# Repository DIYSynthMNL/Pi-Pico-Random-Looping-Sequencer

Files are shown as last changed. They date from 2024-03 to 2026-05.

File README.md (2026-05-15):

# Pi Pico Random Looping Sequencer

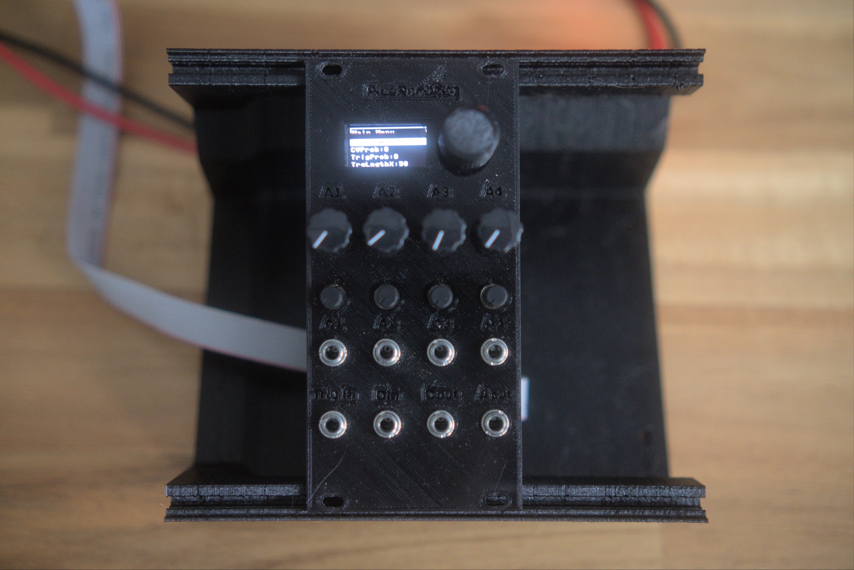
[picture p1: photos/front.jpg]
Pi Pico Random Looping Sequencer powered on


A Raspberry Pi Pico-based Eurorack random / quantized step sequencer with OLED menu, rotary encoder navigation, and **probability-driven variation** on both the CV and trigger sequences. The headline trick: each clock pulse, a configurable probability determines whether the current step's CV (or trigger) gets replaced by a new random value from the chosen musical scale — so the sequence "loops" but slowly mutates as you patch.

Build notes and write-ups on the blog: [diysynthmnl.github.io](https://diysynthmnl.github.io/)

[Demo video on YouTube](https://youtu.be/u1J9JrJe1Y0)

## Features

**Sequencer (firmware):**
- 1 to 16 steps per sequence, user-selectable
- 40+ musical scales (major, minor, dorian, phrygian, blues, pentatonic, hungarian minor, harmonic major, … via [Hector Miller-Bakewell's musical-scales library](https://github.com/hmillerbakewell/musical-scales))
- 1–5 octave CV range
- **CV probability of change** (0–100 %, increments of 5) — how often each step's pitch gets re-randomized on the clock pulse
- **Trigger probability of change** (0–100 %) — same for the trigger output
- **Trigger length** (0–100 % of clock period) — controls gate width
- **CV erase mode** — clamps all steps to scale's root note
- **Trigger erase mode** — sets all triggers to ON
- **Test scale mode** — cycles through scale notes in order (for tuning verification)
- **Tuning scale mode** — alternates between note 12 (1V) and note 24 (2V) (for octave-spacing verification)

**Hardware:**
- 128×64 px SSD1306 OLED display for the menu
- Rotary encoder with push-switch for navigation
- 4 analog parameter inputs (each with jack + attenuator pot + offset pot) → Pico ADC pins
- 1 trigger/clock input
- 1 digital input (for sync, reset, or any gate-like signal)
- 1 digital output (trigger out, with single-transistor buffer to ±5V Eurorack levels)
- 1 quantized CV output via **MCP4725** 12-bit I²C DAC (1V/oct over 5 octaves)
- Eurorack ±12V power (16-pin IDC); local +5V and −5V regulators on board

## Inputs and outputs

| Jack | Function | Wiring |
|---|---|---|
| Analog In 1–4 | Parameter modulation inputs (±5V CV) | Jack → atten (100K) + offset (10K) → MCP6004 → Pico ADC pins GP26–29 |
| Trigger / Clock In | External clock or trigger | Jack → 100K + BAT42 clamps → 2N3904 inverter → GP22 |
| Digital In | Generic digital input (sync, reset, …) | Same topology → GP21 |
| Digital Out | Trigger / gate output | GP23 → 100K → 2N3904 inverter → 10K + 100K → jack |
| vOct Out | Quantized CV (0–5V, 1V/oct) | MCP4725 DAC (I²C, address 0x60) → 100K series → jack |

Front-panel pots / controls:

| Control | Value | Function |
|---|---|---|
| RV2 / RV4 / RV6 / RV8 | 100K | **Analog input attenuator** per channel (1–4) |
| RV1 / RV3 / RV5 / RV7 | 10K | **Analog input offset** per channel (1–4) |
| SW1 | rotary encoder + switch | **Menu navigation** — rotate to scroll items, click to select |

## Pico GPIO pinout (Rev 0.1.0)

| GP | RP2040 function | Connected to | Notes |
|---|---|---|---|
| GP16 | I²C0 SDA | OLED + MCP4725 | Shared bus, both peripherals (addresses 0x3C and 0x60) |
| GP17 | I²C0 SCL | OLED + MCP4725 | Same |
| GP18 | GPIO | Rotary encoder A | |
| GP19 | GPIO | Rotary encoder B | |
| GP20 | GPIO | Rotary encoder switch | Active-low (button to GND) |
| GP21 | GPIO | Digital input | **Inverted** by Q2 2N3904 |
| GP22 | GPIO | Trigger/Clock input | **Inverted** by Q1 2N3904 |
| GP23 | GPIO | Digital output | Drives Q3 2N3904 → jack tip |
| GP26 (ADC0) | ADC | Analog In 4 (per firmware mapping) | |
| GP27 (ADC1) | ADC | Analog In 3 | |
| GP28 (ADC2) | ADC | Analog In 2 | |
| GP29 (ADC3) | ADC | Analog In 1 | **Requires Pico clone with GP29 broken out — see Build notes below** |

## Block diagram

```
                  ╔══════════════════════ HARDWARE ════════════════════╗
                  ║                                                       ║
External CV (±5V) ──[J1–J4]──┬──[RV (100K) atten]──┐                    ║
                              │                    ▼                     ║
                              ▼               [R (100K) summing]         ║
                          [RV (10K) offset]   │                          ║
                               │              │                          ║
                          [+5V/−5V refs]      ▼                          ║
                               │       [MCP6004 inverting amp]           ║
                               └─────────────┤                           ║
                                              │                          ║
                                              ▼ (0 to 3.3V)              ║
                                       Pico GP26–29 (ADC)                 ║
                                                                          ║
Trigger jack ── inverter ──► GP22                                         ║
Digital In   ── inverter ──► GP21                                         ║
                                                                          ║
                  ╔════════════════════ FIRMWARE (MicroPython) ═════════╗
                  ║                                                       ║
                  ║  main loop:                                           ║
                  ║    main_menu.loop_main_menu(update_seq_callback)      ║
                  ║    handle_clock_pulse()  ← detects GP22 edges        ║
                  ║       on rising edge:                                 ║
                  ║         randomly_change_current_step_cv()             ║
                  ║         randomly_change_step_trigger()                ║
                  ║         dac.write(cv_sequence[current_step])          ║
                  ║         current_step += 1 (mod number_of_steps)       ║
                  ║    check_trigger_off()  ← turns off trigger after     ║
                  ║                            trigger_length_ms          ║
                  ║                                                       ║
                  ║  sequencer state:                                     ║
                  ║    cv_sequence[16] = quantized 12-bit DAC values      ║
                  ║    trigger_sequence[16] = 0/1                         ║
                  ║    current_12bit_scale = scale × octaves              ║
                  ║                                                       ║
                  ╚═══════════════════════════════════════════════════════╝
                                              │                          ║
                                              ▼                          ║
GP23 ──► inverter ──► Digital Out jack                                    ║
                                                                          ║
GP16/17 (I²C0) ──► MCP4725 DAC ──► [R23 100K series] ──► vOct Out jack    ║
                                                                          ║
                  ╚═══════════════════════════════════════════════════════╝
```

## Power

- Eurorack ±12V via **J7** (16-pin IDC)
- D6 / D7: reverse-polarity protection
- C4 / C5 (22 µF): bulk rail decoupling on ±12V
- **U3 (78M05): +5V regulator** from +12V → powers MCP4725, Pico VSYS (via D5 BAT42), OLED, transistor pull-ups
- **U4 (79M05): −5V regulator** from −12V → powers the analog input offset network (−5V reference)
- Pico generates its own **+3.3V** (from VSYS via on-board buck converter on the Pico module) → powers MCP6004 op-amps
- C1 / C6 (2.2 µF) regulator output caps, C7 / C3 (100 nF) decoupling

Two power scenarios are supported:
1. **Eurorack power only** — module operates fully
2. **Eurorack + USB** — Pico's USB port can be plugged in concurrently for firmware development. **D5 (BAT42 between +5V rail and Pico VSYS)** prevents USB from back-feeding the Eurorack rail, and prevents Eurorack from feeding the USB host.

## Build notes

### Choose a Pi Pico clone with GP29 (ADC3) broken out

> **This is the most important build decision.** The official Raspberry Pi Pico has GP29 internally tied to VSYS voltage sensing and **is NOT available as an ADC pin**. Many Pico clones (including the one shown in this design, the "Pi Pico Clone Lite Black") break out all 4 ADC pins, including GP29.
>
> If you can't find a clone with GP29 exposed, you have two options:
> - **Reduce to 3 analog inputs** in firmware — omit `cv1 = AnalogueReader(A3)` in `main.py` and adjust the menu / mapping accordingly. The hardware would still have all 4 jacks but the 4th would be unconnected at the Pico.
> - **Use an external ADC** (e.g., MCP3208 over SPI) for the analog inputs — more flexible but requires firmware rework.

Compatible clones tested:
- "Pi Pico Clone Lite Black" — confirmed to have GP29 broken out (used in this design)
- Other clones: check the pinout diagram before buying

### Component selection

- **MCP4725 breakout board** (J8) — common Adafruit / generic breakout, uses I²C address 0x60 (or 0x61, depending on A0 pin). Comes pre-soldered.
- **SSD1306 128×64 OLED** (J… U5) — common eBay / Aliexpress breakout, I²C address 0x3C.
- **MCP6004 quad op-amp** (U1) — rail-to-rail CMOS, runs on +3.3V single supply. DO NOT substitute a TL07x here — those won't swing rail-to-rail and won't reach 0V on the output.

## Calibration

The module has no internal hardware trim pots — calibration is done in software via the firmware's tuning modes.

**Step 1 — Verify 1V/oct tracking using Tuning Scale mode.**

The firmware has a "TuningScale" toggle in the menu. When enabled, it outputs a fixed alternating sequence:

| Step | 12-bit DAC value | Expected voltage at DAC output |
|---|---|---|
| 0 | 816 | 1.000 V (note 12 = first C above 0V) |
| 1 | 1632 | 2.000 V (note 24 = second C) |
| 2 | 816 | 1.000 V |
| ... | ... | ... |

Procedure:
1. Enable TuningScale mode in the menu
2. Patch any clock signal into Trigger/Clock In
3. Scope the vOct Out jack — the output should toggle between two voltages exactly **1.000 V apart**
4. If the spacing is not 1.000 V (typically slightly less, e.g. 0.996 V), the DAC's Vref is slightly off from 5.000 V — see **Design notes — 1V/oct precision** for the math and fix options

**Step 2 — Verify GP29 (ADC3) is working.**

If you're using a clone with GP29 exposed, patch a CV into Analog In 1 (which maps to GP29 / ADC3 per the firmware) and verify it shows up correctly in any analog-input-driven menu (note: as of Rev 0.1.0 of the firmware, analog inputs are wired to hardware but the main loop's analog reading code is `TODO`'d out — see [issue #2](../../issues)).

## Development workflow

1. Power the module via Eurorack (±12V)
2. Plug a USB cable into the Pico (this is safe; D5 prevents back-feeding)
3. Use **VSCode with the [MicroPico extension](https://marketplace.visualstudio.com/items?itemName=paulober.pico-w-go)**
4. Common commands:
   - `MicroPico: Delete all files from pico` — wipe before fresh upload
   - `MicroPico: Upload project files to pico` — sync `Software/` to the Pico
   - `MicroPico: Run` — execute `main.py`

The Pico runs **MicroPython** firmware (not C/C++ SDK). MicroPython is slower but dramatically easier to iterate on — and the timing precision required for a step sequencer (a few ms of clock-edge accuracy) is well within MicroPython's capabilities on the RP2040.

### C++ rewrite (in progress)

A C++ rewrite of the firmware — host-agnostic `SequencerEngine` class plus a macOS playground simulator, with a Pico-SDK host planned — lives in its own repo: [**DIYSynthMNL/Pi-Pico-Random-Looping-Sequencer-Firmware**](https://github.com/DIYSynthMNL/Pi-Pico-Random-Looping-Sequencer-Firmware). The MicroPython firmware in `Software/` is still the running firmware on hardware today.

## Borrowed firmware libraries

Two external libraries are vendored into `Software/lib/`:

- **`analog_reader.py`** — adapted from [EuroPi by Allen Synthesis](https://github.com/Allen-Synthesis/EuroPi) (Apache License 2.0). `AnalogueReader` class with `percent()`, `range()`, `choice()` helpers and over-sampling for noise reduction. Local additions: `invert` flag, `map_value()` helper.
- **`mcp4725_musical_scales.py`** — built on top of [Hector Miller-Bakewell's musical-scales](https://github.com/hmillerbakewell/musical-scales) library (MIT). Defines 40+ scale intervals and a `get_scale_of_12_bit_values()` helper that converts note numbers to MCP4725 DAC counts.

Other vendored libs (`ssd1306.py`, `rotary.py`, `rotary_irq_rp2.py`, `mp_button.py`, `mcp4725.py`) are standard MicroPython drivers — credited in each file's header.

Original code: `main.py`, `menu.py` (custom OLED menu system), `musical_scales.py` (Rex's wrapper around the above).

## Design notes

### 1V/oct precision math

The MCP4725 is a 12-bit DAC with Vref = VCC = 5V (powered from the local 78M05 regulator). Resolution: 5V / 4096 = **1.221 mV per count**.

For 1V/oct over 12 semitones, the ideal step is **83.33 mV per semitone**. The firmware uses `multiplier = 68` counts per semitone → 68 × 1.221 mV = **82.99 mV per semitone** — that's 0.34 mV short, or about **7 cents flat per octave**. Compounded over 5 octaves at the top of the range: ~35 cents flat at the top C.

Fix options (in order of effort):
1. **Use a tuning lookup table** in firmware that adjusts each note's DAC count individually — captures the per-octave error. Requires bench-measured calibration data.
2. **Trim the +5V regulator's output** slightly high (e.g., to 5.083 V) so 4080 counts = 5.000 V exactly. But this affects the OLED and the digital output level too.
3. **Add a 1V/oct gain trim** in hardware: replace R23 with an op-amp buffer + gain trim that scales the DAC output up by ~0.4 %. This is the canonical Eurorack approach.

### MCP4725 output buffering

R23 (100K) is the only thing between the DAC's output pin and the vOct Out jack — **there is no buffer op-amp.** With a typical Eurorack input impedance of 100K, this forms a 1:1 voltage divider that **halves the output voltage**.

**This is a real concern** — needs bench verification:
- Scope J9 with no load → should match the DAC voltage (no divider)
- Scope J9 driving a typical 100K Eurorack input → if voltage is halved, you have ~0.5 V/oct instead of 1 V/oct
- Fix: insert a unity-gain TL07x buffer between the DAC output and R23 (or replace R23 with the buffer)

See [issue #1](../../issues).

### Analog input mapping

The MCP6004 op-amps run from +3.3V single supply. Their output must stay within 0–3.3V to be readable by the Pico's ADC. The input network does the mapping:

```
External CV (±5V) ──[100K attenuator (RV2 fully open)]──┐
                                                        │
+5V/−5V offset ──[10K offset pot]──[100K]──┐            │
                                            │            ▼
                                            ▼      [100K input R]
                                       [100K input R]    │
                                            └───────────┤
                                                        │
                                       (inverting summing junction)
                                                        │
                                                        ▼
                                           [MCP6004 inverting amp, 100K feedback]
                                                        │
                                                        ▼
                                                  Pico ADC (0–3.3V)
```

The math is: at the inverting input, the contributions sum. The op-amp output is `−(V_in/100K + V_offset/100K) × 100K = −(V_in + V_offset)`. With a +5V supply and clamping to 0–3.3V, the effective input range is roughly `+1.7V to −3.3V` external → `0V to 3.3V` at the ADC. This is asymmetric — the input is biased toward processing positive-going CVs.

For symmetric ±5V CV mapping, the offset pot RV1/3/5/7 should be set to bias the op-amp output near 1.65V (mid-range) at 0V external input. Calibration procedure for this is currently undocumented — see [issue #3](../../issues).

## Inspirations and prior art

This module sits in the "random / generative sequencer" family. Direct inspirations:
- **EuroPi (Allen Synthesis)** — the analog reading pattern is borrowed from here; EuroPi is the open-source progenitor of "Pi Pico + Eurorack" modules
- **Music Thing Modular Turing Machine** — the "looping but mutating" concept (Rex's "probability of change" is structurally similar to Turing's "lock probability")
- **Mutable Instruments Marbles** — random CV + trigger generation with probability-of-change parameters

This module is **MicroPython on a Pi Pico** — simpler firmware than EuroPi (which is a full Allen-Synthesis-maintained framework) but with comparable hardware capability.

## References

Local archived copies live in [`references/`](references/) so this repo stays useful if the upstream links die.

- **RP2040 datasheet (Raspberry Pi)** — [local copy](references/RP2040-datasheet.pdf) · [upstream](https://datasheets.raspberrypi.com/rp2040/rp2040-datasheet.pdf)
- **MCP4725 datasheet (Microchip)** — [local copy](references/MCP4725-Microchip.pdf) · [upstream](https://ww1.microchip.com/downloads/en/devicedoc/22039d.pdf) — 12-bit DAC, I²C
- **MCP6001/2/4 datasheet (Microchip)** — [local copy](references/MCP6001-2-4-Microchip.pdf) · [upstream](https://ww1.microchip.com/downloads/aemDocuments/documents/MSLD/ProductDocuments/DataSheets/MCP6001-1R-1U-2-4-1-MHz-Low-Power-Op-Amp-DS20001733L.pdf) — covers the MCP6004 quad op-amp
- [Raspberry Pi Pico full datasheet (with on-module Pico-specific info)](https://datasheets.raspberrypi.com/pico/pico-datasheet.pdf) — not archived locally (17 MB), but worth bookmarking
- [EuroPi project (Allen Synthesis)](https://github.com/Allen-Synthesis/EuroPi) — `analog_reader.py` source
- [musical-scales library (Hector Miller-Bakewell)](https://github.com/hmillerbakewell/musical-scales) — `mcp4725_musical_scales.py` source
- [Build blog: diysynthmnl.github.io](https://diysynthmnl.github.io/) — Rex's running notes on this build

## Build status

What's ready for builders today, and what's still on the TODO list:

**Production assets** (what you need to actually fabricate and assemble a final unit)

- [x] Schematic — Rev 0.1.0 ([pi-pico-random-looping-sequencer-schematic-rev-0.1.0.pdf](Hardware/Schematics/pi-pico-random-looping-sequencer-schematic-rev-0.1.0.pdf))
- [ ] PCB layout — in progress — single working layout in `Hardware/pi-pico-random-looping-sequencer/`, not yet separated for fab
- [ ] Gerber files for fabrication — none yet
- [ ] BOM — none yet
- [ ] Final front panel (SVG/PDF for fab) — none yet
- [x] License — [LICENSE](LICENSE) (MIT)

**Prototype assets** (for breadboard / perfboard / 3D-printed-panel builds before final PCB)

- [x] 3D-printed prototype panel STL — [pico-rand-loop-V2.stl](Hardware/3D%20printed%20panel/pico-rand-loop-V2.stl)

**Firmware**

- [x] Working sequencer firmware — [`Software/main.py`](Software/main.py)
- [x] MicroPython libraries vendored in [`Software/lib/`](Software/lib/)
- [ ] Implement reading from the 4 analog input jacks (currently TODO in main loop — see [issue](../../issues))
- [ ] Per-note tuning lookup table (improves 1V/oct precision — see Design notes)
- [ ] Save/load patterns to flash (currently lost on power-cycle)

**Documentation**

- [x] Photos of the assembled module — see [photos/](photos/)
- [x] Demo video — [watch](https://youtu.be/u1J9JrJe1Y0)
- [ ] Build / assembly instructions — none yet
- [x] Calibration procedure — see Calibration section above

Want to help fill a gap (build photos, gerbers, an assembly guide)? Open an issue or PR.

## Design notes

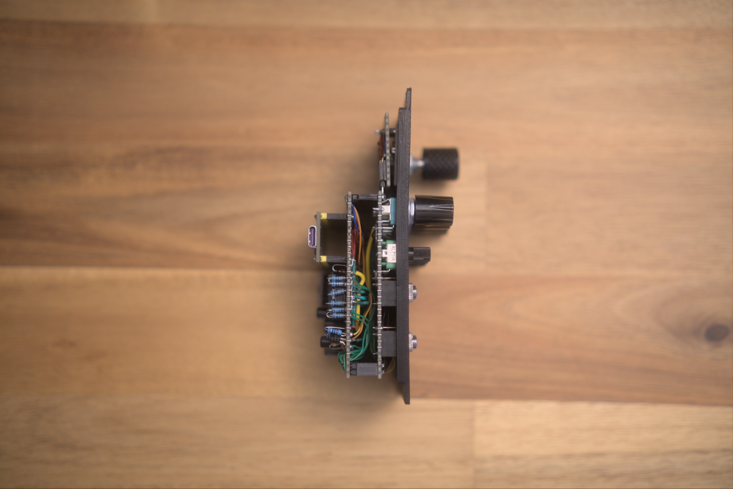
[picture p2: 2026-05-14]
photos/prototype-board-side.jpg

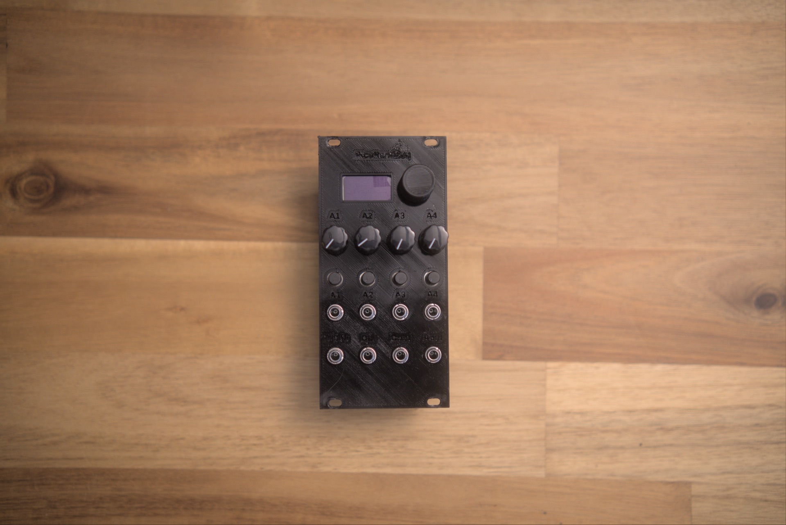
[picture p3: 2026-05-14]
photos/front-flat.jpg

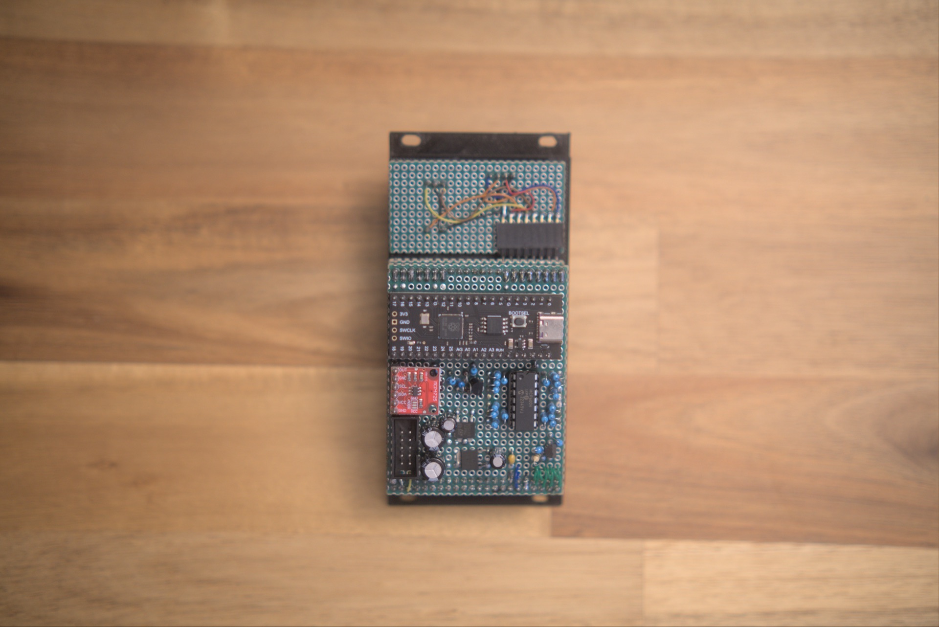
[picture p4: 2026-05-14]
photos/prototype-board.jpg

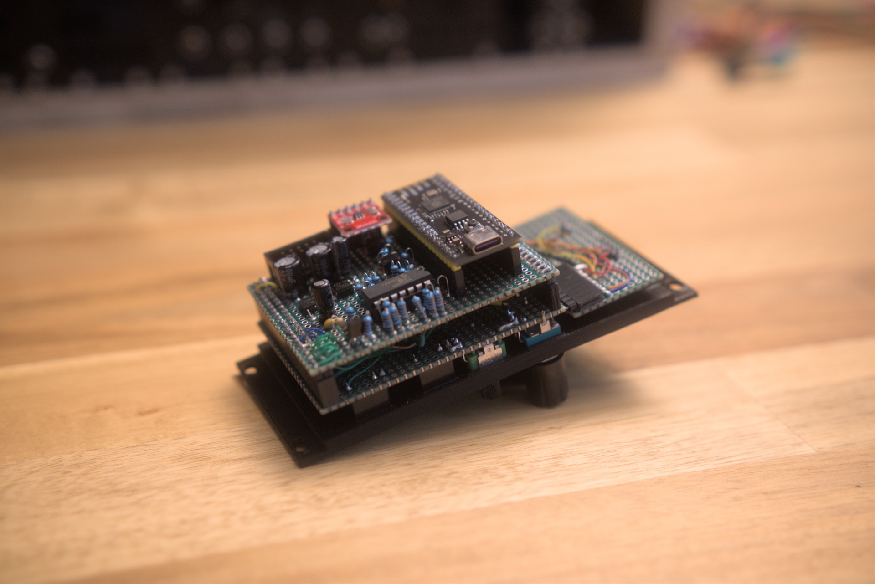
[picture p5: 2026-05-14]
photos/prototype-board-angled.jpg

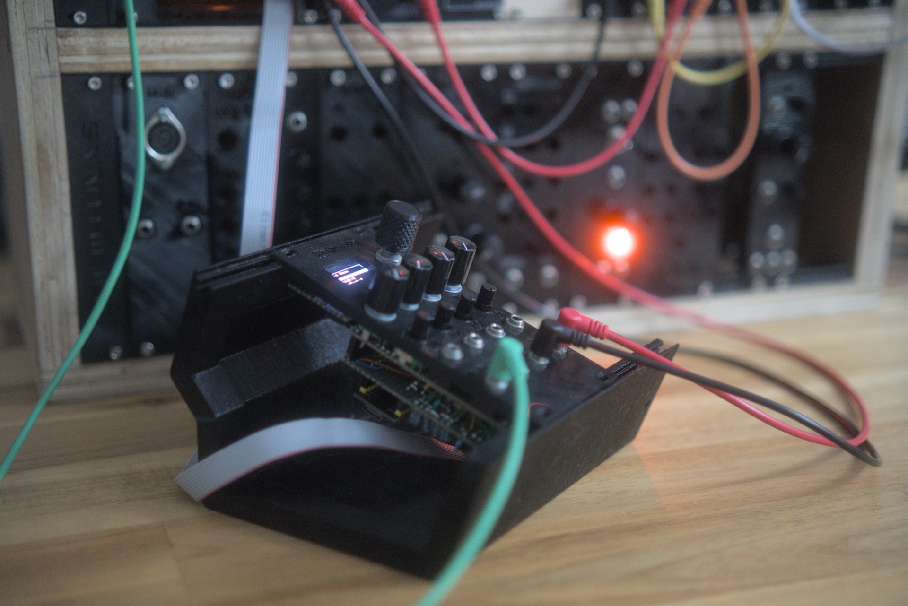
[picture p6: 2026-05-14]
photos/in-rack.jpg

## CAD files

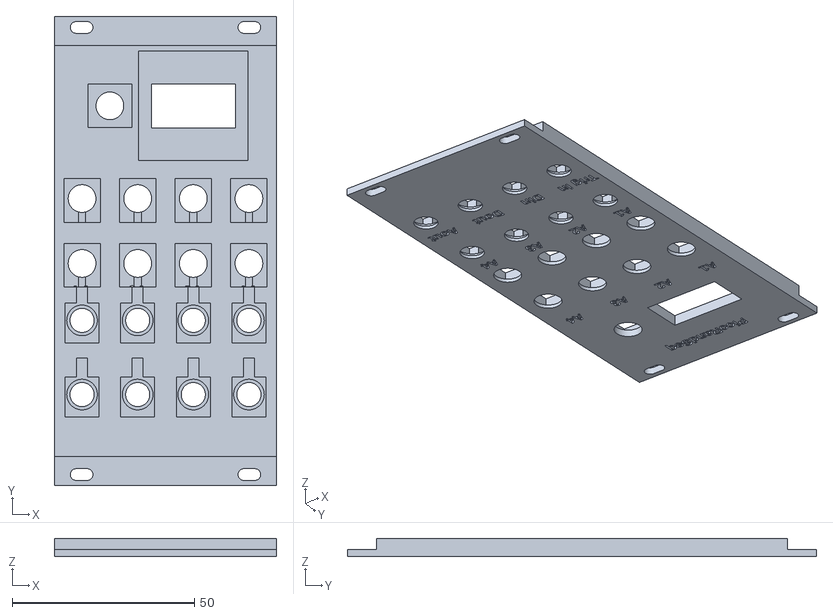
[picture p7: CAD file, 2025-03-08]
Hardware/3D printed panel/pico-rand-loop-V2.stl
61.0 x 128.5 x 5.00

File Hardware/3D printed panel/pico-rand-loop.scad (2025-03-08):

include <EuroPanelMaker/panel.scad>

hp = 12;
title = "PicoRandSeq";
title_font_size = 3;
title_font = "Alte Haas Grotesk:style=bold";
label_font = "Alte Haas Grotesk:style=bold";

panel_flipped=true;
pin_alignment_mode = true;
vertical_mode_254 = true;

jacks = [
[1.5, 16, "A1"],
[4.5, 16, "A2"],
[7.5, 16, "A3"],
[10.5, 16, "A4"],

[1.5, 8, "Trig In"],
[4.5, 8, "Din"],
[7.5, 8, "Dout"],
[10.5, 8, "Aout"],
];

encoders = [
[9, 38, ""] // encoder
];

pots_rd901f = [
// Level
[1.5, 28, "A1"],
[4.5, 28, "A2"],
[7.5, 28, "A3"],
[10.5, 28, "A4"],


// Amplitude
[1.5, 21, ""], //A1
[4.5, 21, ""], //A2
[7.5, 21, ""], //A3
[10.5, 21, ""], //A4
];

rectangular_holes = [
//ssd1306 128x64 px
[4.5, 104, 23, 12, 30, 30]
];
generatePanel();

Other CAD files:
Hardware/3D printed panel/pico-rand-loop.stl

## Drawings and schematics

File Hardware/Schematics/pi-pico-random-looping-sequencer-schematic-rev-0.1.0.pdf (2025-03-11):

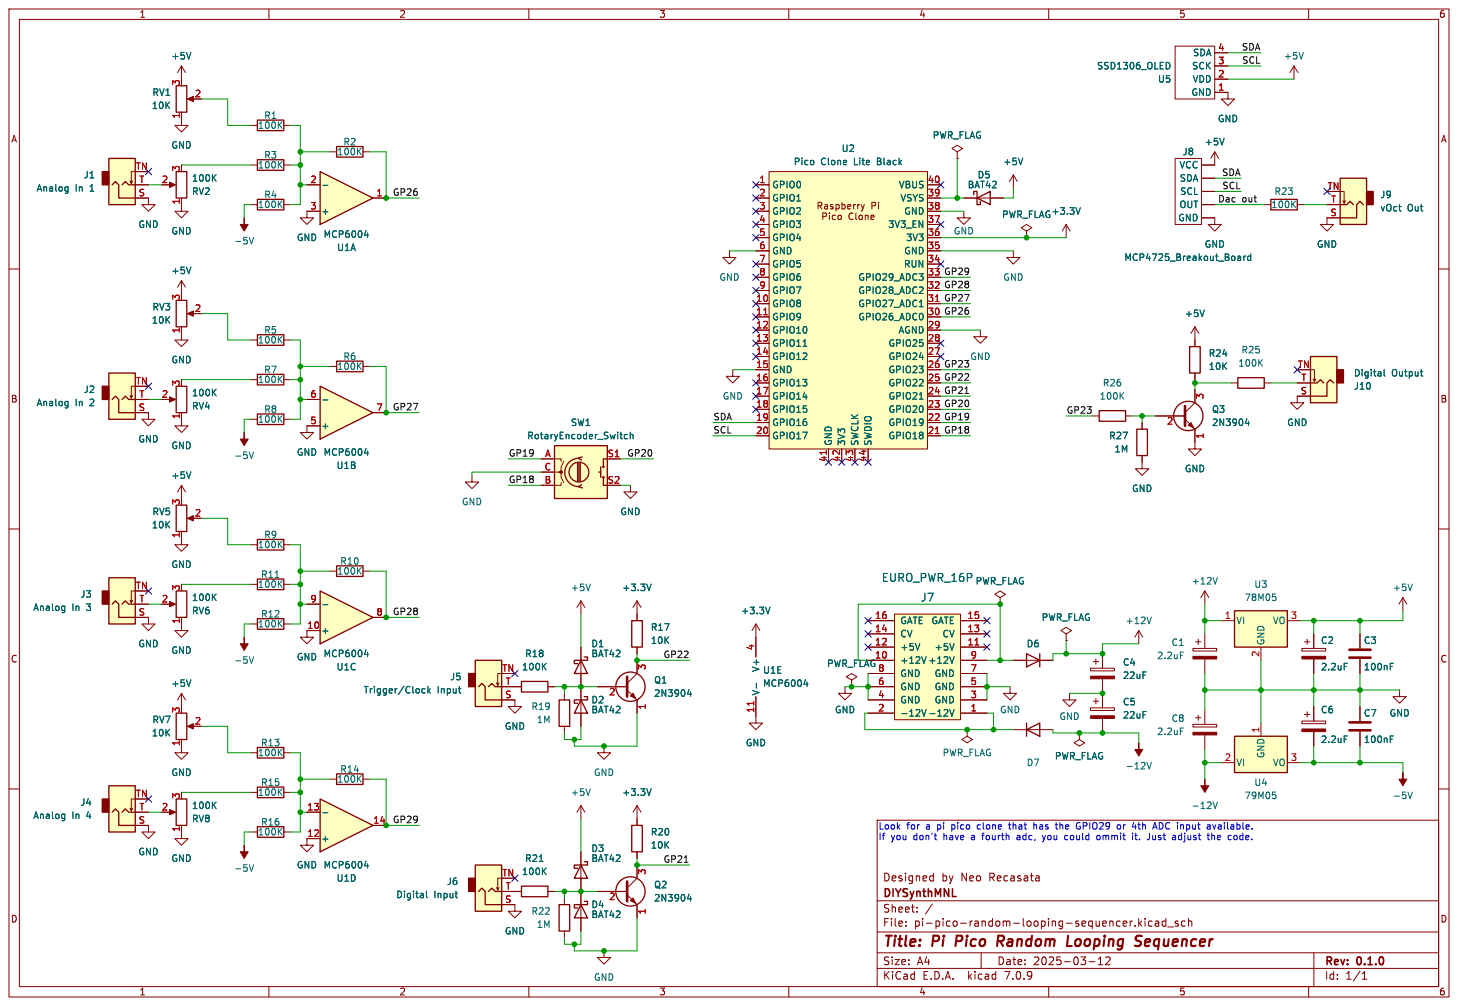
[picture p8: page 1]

J8 MCP4725_Breakout_Board +5V GND
J8 MCP4725_Breakout_Board GND OUT SCL SDA

If you don't have a fourth adc, you could ommit it. Just adjust the code. PWR_FLAG

Look for a pi pico clone that has the GPIO29 or 4th ADC input available.

Id: 1/1 Title: Pi Pico Random Looping Sequencer File: pi-pico-random-looping-sequencer.kicad_sch Sheet: / DIYSynthMNL

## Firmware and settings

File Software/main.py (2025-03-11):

"""
MIT License (MIT)
Copyright (c) 2025 Neo Recasata
https://opensource.org/licenses/MIT

Pi Pico Quantized Random Looping Sequencer (with 128x64 px OLED screen)
By DIYSynthMNL

Wiring:
OLED
OLED SDA to GP16
OLED SCL to GP17
OLED VCC to 3.3V (TODO test 5V)
OLED GND to GND

DAC
DAC SDA to GP16
DAC SCL to GP17
DAC VCC to 5V
DAC GND to GND

Encoder (no breakout board)
ROT Pin 1 to GP19
ROT Pin 2 to GND
ROT Pin 3 to GP18
SW Pin 1 to GND
SW Pin 2 to GP20

Analog inputs
A0 = GP26
A1 = GP27
A2 = GP28
A3 = GP29

TODO: implement control voltage input to change variables
TODO: Schematic
"""

import machine
import mcp4725
import mcp4725_musical_scales as sc
import random
import menu as m
import analog_reader as analog_reader
from analog_reader import AnalogueReader
import time

# pins
sda = 16
scl = 17
digital_input_pin = 21  # inverted
clock_input_pin = 22  # inverted
digital_output_pin = 23  # inverted
A0 = 26
A1 = 27
A2 = 28
A3 = 29

# i2c
i2c_channel = 0
i2c = machine.I2C(i2c_channel, sda=machine.Pin(sda), scl=machine.Pin(scl))
dac = mcp4725.MCP4725(i2c, mcp4725.BUS_ADDRESS[0])

# setup pins
clock_in = machine.Pin(clock_input_pin, machine.Pin.IN, machine.Pin.PULL_DOWN)
digital_in = machine.Pin(digital_input_pin, machine.Pin.IN, machine.Pin.PULL_DOWN)
digital_out = machine.Pin(
    digital_output_pin, machine.Pin.OUT, machine.Pin.PULL_DOWN, value=0
)

# sequencer variables
MAX_NUMBER_OF_STEPS = 16
MIN_NUMBER_OF_STEPS = 2
MAX_NUMBER_OF_OCTAVES = 5
MIN_NUMBER_OF_OCTAVES = 1
cv_sequence = []
trigger_sequence = []
tuning_cv_sequence = [
    816,
    1632,
    816,
    1632,
    816,
    1632,
    816,
    1632,
    816,
    1632,
    816,
    1632,
    816,
    1632,
    816,
    1632,
]
test_cv_sequence = []
current_step = 0
number_of_steps = 16  # user can edit from 1 to any
step_changed_on_clock_pulse = False
cv_probability_of_change = 0  # user can edit 0 to 100
trigger_probability_of_change = 0
trigger_length_percent = 50
trigger_start_ticks = 0
previous_clock_ticks = 0
trigger_active = False
clock_ms = 0
trig_length_ms = 0
ticks_to_trigger_off = 0
is_cv_erase = False
is_trig_erase = False
is_test_cv_sequence = False
is_tuning_cv_sequence = False

# scales
scale_intervals = sc.get_intervals()
current_scale_interval = "major"
starting_note = 12  # start at the next octave to prevent low voltage output issues (the note 0 will not be in tune) refer to the mcp4725 1vOct table
number_of_octaves = 1
current_12bit_scale = sc.get_scale_of_12_bit_values(
    scale_interval=current_scale_interval,
    starting_note=starting_note,
    octaves=number_of_octaves,
)

# menu
main_menu = m.MainMenu()

scale_menu = m.SingleSelectVerticalScrollMenu(
    "Scale",
    button=main_menu.button,
    selected=current_scale_interval,
    items=scale_intervals,
)

cv_prob_menu = m.NumericalValueRangeMenu(
    "CVProb", button=main_menu.button, selected=cv_probability_of_change, increment=5
)

trig_prob_menu = m.NumericalValueRangeMenu(
    "TrigProb",
    button=main_menu.button,
    selected=trigger_probability_of_change,
    increment=5,
)

trig_length_menu = m.NumericalValueRangeMenu(
    "TrgLngth%",
    button=main_menu.button,
    selected=trigger_length_percent,
    increment=10,
)

steps_menu = m.NumericalValueRangeMenu(
    "Steps",
    button=main_menu.button,
    selected=number_of_steps,
    increment=1,
    min_val=MIN_NUMBER_OF_STEPS,
    max_val=MAX_NUMBER_OF_STEPS,
)

octaves_menu = m.NumericalValueRangeMenu(
    "Octaves",
    button=main_menu.button,
    selected=number_of_octaves,
    increment=1,
    min_val=MIN_NUMBER_OF_OCTAVES,
    max_val=MAX_NUMBER_OF_OCTAVES,
)

starting_note_menu = m.NumericalValueRangeMenu(
    "Start note",
    button=main_menu.button,
    selected=0,
    increment=1,
    min_val=0,
    max_val=36,
)

cv_erase_toggle_menu = m.ToggleMenu(
    "CvErase", button=main_menu.button, value=is_cv_erase
)

trig_erase_toggle_menu = m.ToggleMenu(
    "TrigErase", button=main_menu.button, value=is_trig_erase
)

test_cv_scale_toggle_menu = m.ToggleMenu(
    "TestScale", button=main_menu.button, value=is_test_cv_sequence
)

is_tuning_cv_scale_menu = m.ToggleMenu(
    "TuningScale", button=main_menu.button, value=is_tuning_cv_sequence
)

submenus = [
    scale_menu,
    cv_prob_menu,
    trig_prob_menu,
    trig_length_menu,
    steps_menu,
    octaves_menu,
    starting_note_menu,
    cv_erase_toggle_menu,
    trig_erase_toggle_menu,
    test_cv_scale_toggle_menu,
    is_tuning_cv_scale_menu,
]
main_menu.set_submenus(submenu_list=submenus)

# analog inputs
cv1 = AnalogueReader(A3)
cv2 = AnalogueReader(A2)
cv3 = AnalogueReader(A1)
cv4 = AnalogueReader(A0)


def handle_clock_pulse() -> None:
    global current_step, step_changed_on_clock_pulse, clock_in, number_of_steps, previous_clock_ticks, clock_ms, trigger_start_ticks, trigger_active, ticks_to_trigger_off

    current_clock_ticks = time.ticks_ms()

    if current_step < number_of_steps:
        if clock_in.value() == 0 and not step_changed_on_clock_pulse:
            # Clock rising edge detected
            previous_clock_ticks = current_clock_ticks
            test_cv_sequence = get_test_sequence()  # Update CV sequence
            step_changed_on_clock_pulse = True

            randomly_change_current_step_cv()
            randomly_change_step_trigger()

            if is_cv_erase:
                cv_sequence[current_step] = current_12bit_scale[0]

            if is_trig_erase:
                trigger_sequence[current_step] = 1

            # Output the CV value
            if is_test_cv_sequence:
                dac.write(test_cv_sequence[current_step])
            elif is_tuning_cv_sequence:
                dac.write(tuning_cv_sequence[current_step])
            else:
                dac.write(cv_sequence[current_step])

            # Calculate trigger length
            trig_length_ms = (clock_ms * trigger_length_percent) // 100
            # print("Trigger length ms:", trig_length_ms)

            # Trigger output logic
            if trigger_sequence[current_step] == 1:
                digital_out.value(0)  # Turn on trigger
                trigger_start_ticks = time.ticks_ms()  # Store trigger start time

                # print("Trigger on")
                # print("Trigger start ticks", trigger_start_ticks)

                # calculate trigger off ticks
                ticks_to_trigger_off = time.ticks_add(
                    trig_length_ms, trigger_start_ticks
                )
                trigger_active = True  # Mark trigger as active

            current_step += 1

        if clock_in.value() == 1 and step_changed_on_clock_pulse:
            # Clock falling edge detected
            step_changed_on_clock_pulse = False
            clock_ms = time.ticks_diff(current_clock_ticks, previous_clock_ticks)
            # print("Clock length ms:", clock_ms)
    else:
        current_step = 0


def check_trigger_off():
    """Turn off the trigger when the time is reached."""
    global trigger_active, trigger_start_ticks, trig_length_ms, ticks_to_trigger_off
    current_ticks = time.ticks_ms()
    if trigger_active:
        if current_ticks >= ticks_to_trigger_off:
            # print("trigger off")
            digital_out.value(1)  # Turn off trigger
            trigger_active = False  # Reset trigger state


def randomly_change_current_step_cv() -> None:
    # get random index of scale chosen
    random_scale_index = random.randint(0, len(current_12bit_scale) - 1)
    # set cv from scale list
    if generate_boolean_with_probability(cv_probability_of_change):
        # print("change cv")
        cv_sequence[current_step] = current_12bit_scale[random_scale_index]


def randomly_change_step_trigger() -> None:
    global trigger_sequence
    trig_on_or_off = random.randint(0, 1)
    if generate_boolean_with_probability(trigger_probability_of_change):
        trigger_sequence[current_step] = trig_on_or_off


def generate_boolean_with_probability(probability: float) -> bool:
    """
    Returns True or False based on the given probability.

    :param probability: The probability of returning True, in the range [0, 100].
    :type probability: float
    :return: True with probability `probability`, False otherwise.
    :rtype: bool
    """
    if not 0 <= probability <= 100:
        raise ValueError("Probability must be between 0 and 100")

    return random.random() * 100 <= probability


def populate_sequence_with_default() -> None:
    global cv_sequence, current_12bit_scale, MAX_NUMBER_OF_STEPS
    for _ in range(0, MAX_NUMBER_OF_STEPS):
        cv_sequence.append(current_12bit_scale[0])
        trigger_sequence.append(1)


def get_test_sequence() -> list[int]:
    sequence = []
    while len(sequence) < MAX_NUMBER_OF_STEPS:
        for cv_value in current_12bit_scale:
            if len(sequence) < MAX_NUMBER_OF_STEPS:
                sequence.append(cv_value)
    # print(sequence)
    return sequence


def update_sequencer_values() -> None:
    """
    Once the submenu's value is changed (rotary button clicked) it should update the global varable changed
    Updates sequencer values such as:
        scale,
        cv probability,
        number of steps,
        number of octaves
    """
    global current_12bit_scale, cv_probability_of_change, trigger_probability_of_change, number_of_steps, current_scale_interval, number_of_octaves, starting_note, is_test_cv_sequence, test_cv_sequence, is_cv_erase, is_tuning_cv_sequence, trigger_length_percent, is_trig_erase
    print("update_sequencer_values")
    submenus = main_menu.get_submenu_list()
    for submenu in submenus:
        if submenu.name is scale_menu.name:
            if current_scale_interval != submenu.selected:
                current_scale_interval = submenu.selected
                print("Scale changed:", current_scale_interval)

        elif submenu.name is cv_prob_menu.name:
            if cv_probability_of_change != submenu.selected:
                cv_probability_of_change = submenu.selected
                print("CV probability changed:", cv_probability_of_change)

        elif submenu.name is trig_prob_menu.name:
            if trigger_probability_of_change != submenu.selected:
                trigger_probability_of_change = submenu.selected
                print("Trig probability changed:", trigger_probability_of_change)

        elif submenu.name is trig_length_menu.name:
            if trigger_length_percent != submenu.selected:
                trigger_length_percent = submenu.selected
                print("Trig length changed:", trigger_length_percent)

        elif submenu.name is steps_menu.name:
            if number_of_steps != submenu.selected:
                number_of_steps = submenu.selected
                print("Number of steps changed", number_of_steps)

        elif submenu.name is octaves_menu.name:
            if number_of_octaves != submenu.selected:
                number_of_octaves = submenu.selected
                print("Number of octaves changed:", number_of_octaves)

        elif submenu.name is starting_note_menu.name:
            if starting_note != submenu.selected:
                starting_note = submenu.selected
                print("Starting note changed:", starting_note)

        elif submenu.name is cv_erase_toggle_menu.name:
            if is_cv_erase != submenu.value:
                is_cv_erase = submenu.value
                print("ToggleMenu changed:", submenu.value)

        elif submenu.name is trig_erase_toggle_menu.name:
            if is_trig_erase != submenu.value:
                is_trig_erase = submenu.value
                print("ToggleMenu changed:", submenu.value)

        elif submenu.name is test_cv_scale_toggle_menu.name:
            if is_test_cv_sequence != submenu.value:
                is_test_cv_sequence = submenu.value
                print("ToggleMenu changed:", submenu.value)

        elif submenu.name is is_tuning_cv_scale_menu.name:
            if is_tuning_cv_sequence != submenu.value:
                is_tuning_cv_sequence = submenu.value
                print("ToggleMenu changed:", submenu.value)

        else:
            pass
            # print("Error, menu to be updated does not exist!")

    current_12bit_scale = sc.get_scale_of_12_bit_values(
        starting_note=starting_note + 12,
        scale_interval=current_scale_interval,
        octaves=number_of_octaves,
    )


# initialize sequencer
test_cv_sequence = get_test_sequence()
populate_sequence_with_default()
print("Current scale:", current_12bit_scale)
print("Sequence:", cv_sequence)

# previous_cv1_value = 0

# loop
while True:
    # todo implement analog input
    # cv1_value = cv1.choice(list(range(0, 101, 5)), deadzone=0.1)

    # if previous_cv1_value != cv1_value:
    #     # cv1 changed
    #     cv_probability_of_change = cv1_value
    #     # cv_prob_menu.set_selected(cv_probability_of_change)
    #     # main_menu.initialize_main_menu()
    #     previous_cv1_value = cv1_value

    main_menu.loop_main_menu(
        update_main_program_values_callback=update_sequencer_values
    )
    handle_clock_pulse()
    check_trigger_off()

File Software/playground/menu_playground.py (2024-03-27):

"""
Menu Playground

Wiring:
OLED
OLED SDA to GP16
OLED SCL to GP17
OLED VCC to 3.3V or 5V (VBUS)
OLED GND to GND

Encoder (no breakout board)
ROT Pin 1 to GP19
ROT Pin 2 to GND
ROT Pin 3 to GP18
SW Pin 1 to GND
SW Pin 2 to GP20
"""

import mcp4725_musical_scales
import menu as m


scale_intervals = mcp4725_musical_scales.get_intervals()

scale_menu = m.SingleSelectVerticalScrollMenu(
    "Scale", selected="chromatic", items=scale_intervals
)

cv_prob_menu = m.NumericalValueRangeMenu("CVProb", selected=50, increment=5)

steps_menu = m.NumericalValueRangeMenu(
    "Steps", selected=1, increment=1, min_val=1, max_val=16
)

submenus = [scale_menu, cv_prob_menu, steps_menu]

current_menu = scale_menu

m.set_submenus(submenu_list=submenus)

while True:
    # TODO if submenus are changed, update submenus
    submenus = m.get_submenu_list()

    m.loop_main_menu()

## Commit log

2024-03-25 implemented rotary encoder in menu.py
2025-03-08 Add 3d printed panel files
    [pico-rand-loop-V2.stl, pico-rand-loop.scad, pico-rand-loop.stl]
2025-03-10 Trigger length logic fixed
    [main.py]
2025-03-11 Move files into own specific folder
    [pico-rand-loop-V2.stl, pico-rand-loop.scad, pico-rand-loop.stl]
2025-03-11 Add schematic
    [pi-pico-random-looping-sequencer.kicad_pcb, pi-pico-random-looping-sequencer.kicad_sch]
2026-05-14 Add photos/ placeholder for assembled-module shots
2026-05-14 Add assembled-module photos; hero front.jpg
2026-05-14 Deep-dive rewrite: README with hardware + firmware analysis and references/ folder
    Restructures the README to the standard module layout (features,
    I/O table, GPIO pinout, block diagram, power, build notes, calibration,
    development workflow, borrowed firmware libs, design notes,
    references, build status).
    Adds references/ folder with RP2040, MCP4725, and MCP6004 datasheets.
    Design notes call out two real concerns:
    1. MCP4725 → vOct Out has no buffer; R23 (100K) + 100K load halves
    the voltage, breaking 1V/oct tracking (issue #1)
    2. 12-bit DAC at 5V Vref gives ~7 cents flat per octave (issue #4)
    Plus the GP29 ADC Pico-clone requirement (issue #5) is the most likely
    build pitfall — no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
2026-05-15 Add Firmware/ macOS playground: C++ port of sequencer engine + GLFW/ImGui simulator
    Host-agnostic SequencerEngine class (no machine.*, no GPIO, no pico/stdlib.h)
    takes now_ms from the host — same code can later link into a Pico-SDK main.cpp.
    Files:
    SequencerEngine.h/.cpp port of main.py logic (clock-edge driven, probability
    rolls, trig-length timer, test/tuning sequences)
    Scales.h 46 scale intervals from mcp4725_musical_scales.py
    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
2026-05-15 Move firmware C++ rewrite out of Firmware/ — now lives in its own repo
    The new repo at DIYSynthMNL/Pi-Pico-Random-Looping-Sequencer-Firmware
    hosts the host-agnostic SequencerEngine + macOS playground (and will
    host the Pico-SDK main.cpp). Added a pointer to the README's
    Development workflow section.
